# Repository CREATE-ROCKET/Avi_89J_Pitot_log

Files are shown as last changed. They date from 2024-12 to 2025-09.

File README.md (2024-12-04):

# 89Jのピトー管基板用です

## 現在の予定
基本的にFree RTOSでのタスク機能を利用して
 - ピトー管からデーターを得るタスク
 - それを他に送るタスク(CAN、 SPIFlash、 パリティ)
 - CANを送信するタスク
 - SPIFlashに書き込むタスク
 - MicroSDに書き込むタスク

の4つをタスクとして動作させたい。
MicroSDにログを書き込むようのタスクも作るか考え中

```mermaid
flowchart TB
  node_1("getPitotData")
  node_2("sendDataToEveryIC")
  node_3("writeDataToFlash")
  node_4("sendDataByCan")
  node_6("writeDataToSD")
  node_2 --> node_4
  node_2 --> node_3
  node_1 --> node_2
  node_2 --> node_6
```

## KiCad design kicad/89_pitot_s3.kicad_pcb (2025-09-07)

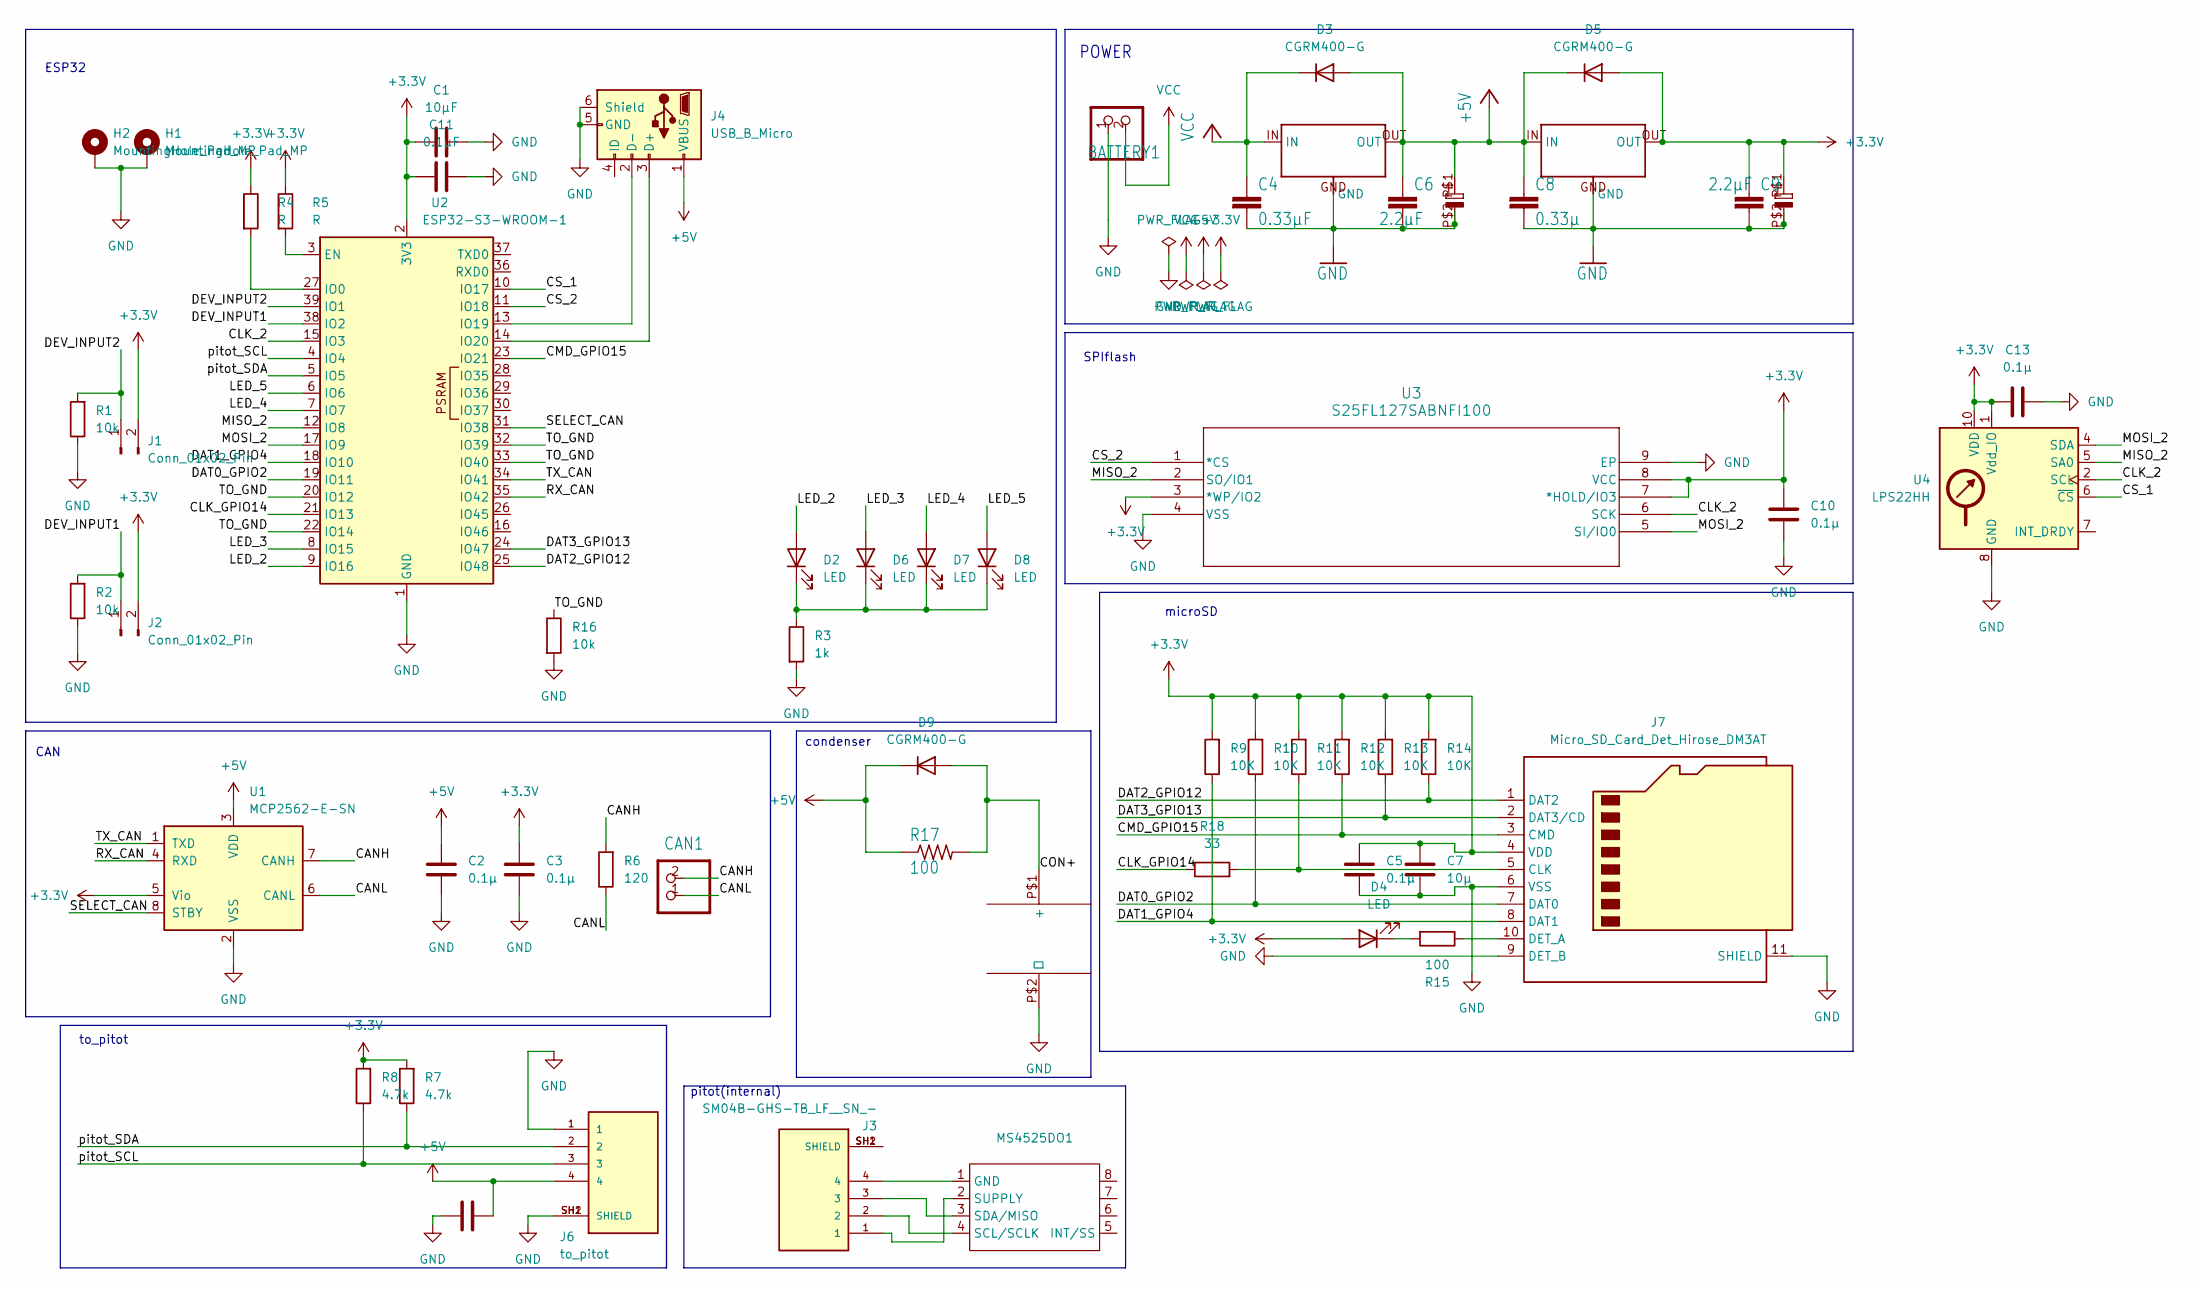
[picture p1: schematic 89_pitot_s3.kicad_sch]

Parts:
BATTERY1: L2; ILG2pin
C1: 10μF; C_0603_1608Metric
C2, C3, C5, C10, C12, C13: 0.1μ; C_0603_1608Metric
C4: 0.33μF; R_0603_1608Metric
C6, C9: 2.2μF; R_0603_1608Metric
C7: 10μ; D_0603_1608Metric
C8: 0.33μ; R_0603_1608Metric
C11: 0.1μF; C_0603_1608Metric
CAN1: ILG2pin
D2, D4, D6, D7, D8: LED; LED_0603_1608Metric
D3, D5, D9: CGRM400-G; D_0603_1608Metric_Pad1.05x0.95mm_HandSolder
H1, H2: MountingHole_Pad_MP; SolderWirePad_1x01_SMD_1x2mm
J1, J2: Conn_01x02_Pin; PinHeader_1x02_P2.54mm_Vertical
J3: SM04B-GHS-TB_LF__SN_-; JST_SM04B-GHS-TB_LF__SN_-; PARTREV NA
J4: USB_B_Micro; USB_Micro-B_Molex_47346-0001
J6: to_pitot; JST_GH_SM04B-GHS-TB_1x04-1MP_P1.25mm_Horizontal; PARTREV NA
J7: Micro_SD_Card_Det_Hirose_DM3AT; microSD_HC_Hirose_DM3AT-SF-PEJM5
MS4525DO1: (no value)
R1, R2: 10k; R_0603_1608Metric
R3: 1k; R_0603_1608Metric
R4, R5: R; C_0603_1608Metric
R6: 120; R_0603_1608Metric
R7, R8: 4.7k; R_0603_1608Metric
R9, R10, R11, R12, R13, R14: 10K; R_0603_1608Metric
R15: 100; R_0603_1608Metric
R16: 10k; C_0603_1608Metric
R17: 100; C_0603_1608Metric
R18: 33; C_0603_1608Metric
U1: MCP2562-E-SN; SOIC-8_3.9x4.9mm_P1.27mm
U2: ESP32-S3-WROOM-1
U3: S25FL127SABNFI100; SOC008_SPA
U4: LPS22HH; ST_HLGA-10_2x2mm_P0.5mm_LayoutBorder3x2y
U$1, U$3: NJM2391DL1-33; DPAK229P990X238-4N
U$2, U$4: UCD0J470MCL1GS; PCAP_5x5.8-ELECT_NCA
U$5: VEC5R4355QG-I; C_Disc_D8.0mm_W5.0mm_P5.00mm

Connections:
+3.3V: C1.1, C3.1, C5.1, C7.1, C9.1, C10.1, C11.1, C13.1, D4.2 (A), D5.2 (A), J1.2, J2.2, J7.4 (VDD), R4.1, R5.1, R7.2, R8.2, R9.2, R10.2, R11.2, R12.2, R13.2, R14.2, U1.5 (Vio), U2.2 (3V3), U3.3 (*WP/IO2), U3.7 (*HOLD/IO3), U3.8 (VCC), U4.1 (Vdd_IO), U4.10 (VDD), U$3.OUT, U$4.P$1 (+)
+5V: C2.1, C6.1, C8.1, C12.2, D3.2 (A), D5.1 (K), D9.1 (K), J4.1 (VBUS), J6.4, R17.1, U1.3 (VDD), U$1.OUT, U$2.P$1 (+), U$3.IN
/CANH: CAN1.2, R6.2, U1.7 (CANH); also elsewhere on the board
/CANL: CAN1.1, R6.1, U1.6 (CANL); also elsewhere on the board
/CLK_2: U2.15 (IO3), U3.6 (SCK), U4.2 (SCL)
/CLK_GPIO14: R18.1, U2.21 (IO13)
/CMD_GPIO15: J7.3 (CMD), R12.1, U2.23 (IO21)
/CON+: D9.2 (A), R17.2, U$5.P$1 (+)
/CS_1: U2.10 (IO17), U4.6 (~CS)
/CS_2: U2.11 (IO18), U3.1 (*CS)
/DAT0_GPIO2: J7.7 (DAT0), R10.1, U2.19 (IO11)
/DAT1_GPIO4: J7.8 (DAT1), R9.1, U2.18 (IO10)
/DAT2_GPIO12: J7.1 (DAT2), R14.1, U2.25 (IO48)
/DAT3_GPIO13: J7.2 (DAT3/CD), R13.1, U2.24 (IO47)
/DEV_INPUT1: J2.1, R2.2, U2.38 (IO2)
/DEV_INPUT2: J1.1, R1.2, U2.39 (IO1)
/LED_2: D2.2 (A), U2.9 (IO16)
/LED_3: D6.2 (A), U2.8 (IO15)
/LED_4: D7.2 (A), U2.7 (IO7)
/LED_5: D8.2 (A), U2.6 (IO6)
/MISO_2: U2.12 (IO8), U3.2 (SO/IO1), U4.5 (SA0)
/MOSI_2: U2.17 (IO9), U3.5 (SI/IO0), U4.4 (SDA)
/RX_CAN: U1.4 (RXD), U2.35 (IO42)
/SELECT_CAN: U1.8 (STBY), U2.31 (IO38)
/TO_GND: R16.1, U2.20 (IO12), U2.22 (IO14), U2.32 (IO39), U2.33 (IO40)
/TX_CAN: U1.1 (TXD), U2.34 (IO41)
/pitot_SCL: J6.3, R8.1, U2.4 (IO4)
/pitot_SDA: J6.2, R7.1, U2.5 (IO5)
GND: BATTERY1.1, C1.2, C2.2, C3.2, C4.2, C5.2, C6.2, C7.2, C8.2, C9.2, C10.2, C11.2, C12.1, C13.2, H1.MP, H2.MP, J4.5 (GND), J4.6 (Shield), J6.1, J6.SH1 (SHIELD), J6.SH2 (SHIELD), J7.6 (VSS), J7.9 (DET_B), J7.11 (SHIELD), R1.1, R2.1, R3.2, R16.2, U1.2 (VSS), U2.1 (GND), U2.40 (GND), U2.41 (GND), U3.4 (VSS), U3.9 (EP), U4.3 (GND), U4.8 (GND), U4.9 (GND), U$1.GND, U$2.P$2 (ー), U$3.GND, U$4.P$2 (ー), U$5.P$2 (ー); also elsewhere on the board
unnamed: D2.1 (K), D6.1 (K), D7.1 (K), D8.1 (K), R3.1
unnamed: D4.1 (K), R15.2
unnamed: J3.1, MS4525DO1.2 (SUPPLY)
unnamed: J3.2, MS4525DO1.4 (SCL/SCLK)
unnamed: J3.3, MS4525DO1.3 (SDA/MISO)
unnamed: J3.4, MS4525DO1.1 (GND)
unnamed: J3.SH1 (SHIELD), J3.SH2 (SHIELD)
unnamed: J4.3 (D+), U2.14 (IO20)
unnamed: J4.2 (D-), U2.13 (IO19)
unnamed: J7.5 (CLK), R11.1, R18.2
unnamed: J7.10 (DET_A), R15.1
unnamed: R5.2, U2.3 (EN)
unnamed: R4.2, U2.27 (IO0)
VCC: BATTERY1.2, C4.1, D3.1 (K), U$1.IN; also elsewhere on the board

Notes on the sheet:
POWER
pitot(internal)
condenser
microSD
ESP32
to_pitot
SPIflash
CAN

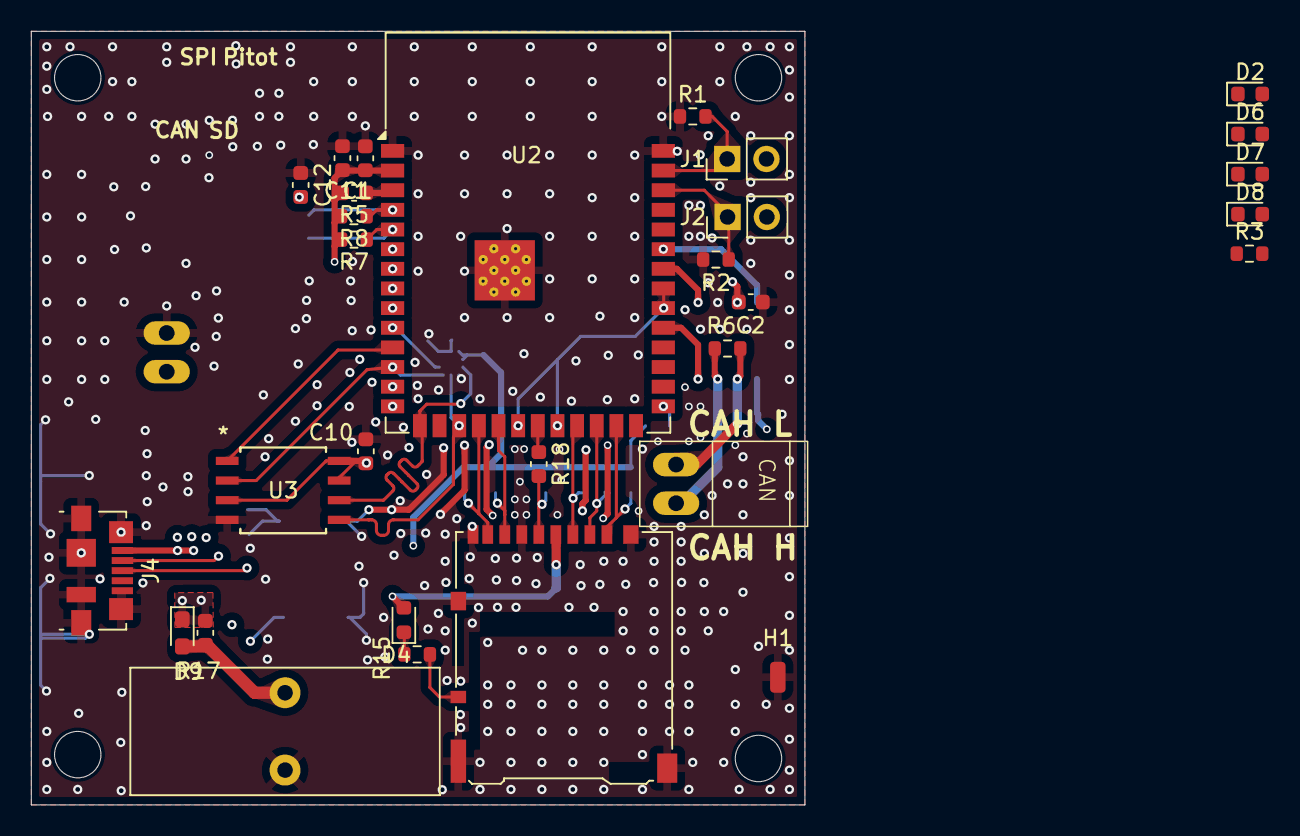
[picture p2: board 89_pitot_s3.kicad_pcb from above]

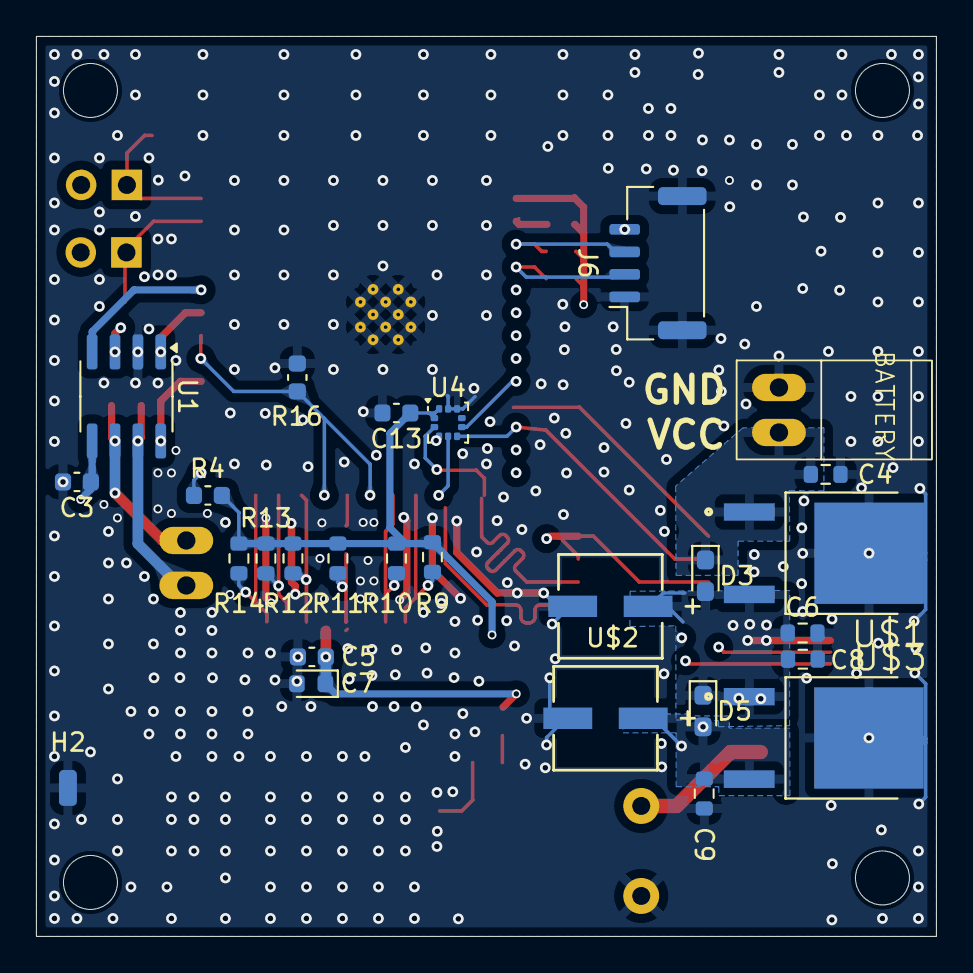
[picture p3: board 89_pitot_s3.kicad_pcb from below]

Board: 8 copper layers, 50.0 x 50.0 mm, 57 parts (27 on the bottom side), 38 nets.

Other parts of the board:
BATTERY: L2; ILG2pin
CAN: ILG2pin

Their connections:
/CANH: CAN.2; also elsewhere on the board
/CANL: CAN.1; also elsewhere on the board
GND: BATTERY.1; also elsewhere on the board
VCC: BATTERY.2; also elsewhere on the board

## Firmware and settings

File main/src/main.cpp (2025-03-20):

// 89ピトー管基板用のコードです。
//
// ピトー管用I2C通信
//    SDA:    IO21
//    SCL:    IO22
//
// SPI flash
//    CS:     IO5
//    CLK:    IO18
//    MOSI:   IO23
//    MISO:   IO19
//
// SD_MMC
//    CLK:    IO14
//    DAT0:   IO2
//    DAT1:   IO4
//    DAT2:   IO12
//    DAT3:   IO13
//    CMD:    IO15
//
// CAN
//    TX:     IO25
//    RX:     IO26
//    SELECT: IO33
//
// LED
//    IO27
//    IO32
//
// DEBUG_INPUT
//    IO17    task1,

#include <Arduino.h>
#include <esp_task_wdt.h>
#include "lib.h"
#include "debug.h"
#include "task_queue.h"
#include "task.h"
#include "panic_wrapper.h"
#include "common_task.h"
#include "interfaces/pitot.h"
#include "interfaces/SD_fast.h"
#include "interfaces/flash.h"
#include "interfaces/CAN_MCP2562.h"
#include "freertos/task.h"

// task handle
TaskHandle_t getPitotDataTaskHandle;      // pitotからデータを取得し、それをsendDataToEveryICへ送る 優先度 -1
TaskHandle_t sendDataToEveryICTaskHandle; // getPitotDataから得たデータを各端末に送る
TaskHandle_t writeDataToFlashTaskHandle;  // SPI_Flashにデーターを書き込む
TaskHandle_t makeParityTaskHandle;        // sendDataToEveryICから受け取ったデータを加工してwriteDataToSDに送る
TaskHandle_t writeDataToSDTaskHandle;     // makeParityから受け取ったデータやログをMicroSDに書き込む
TaskHandle_t sendDataByCanTaskHandle;     // sendDataToEveryICから受け取ったデータを送る

// queue handle
QueueHandle_t PitotToDistributeQueue;  // PitotからsendDataにデータを渡すQueue
QueueHandle_t DistributeToFlashQueue;  // sendDataからFlashにデータを渡すQueue
QueueHandle_t DistributeToParityQueue; // sendDataからParityにデータを渡すQueue
QueueHandle_t ParityToSDQueue;         // ParityからSDにデータを渡すQueue
QueueHandle_t DistributeToCanQueue;    // sendDataからCanにデータを渡すQueue

// 初期化が成功したかどうかを表す
// pitotが0
// SDが1
// flashが2
// CANが3
uint8_t IsInitSuccess = 0;

#ifdef DEBUG

void pr_feature_fg()
{
  Serial.println("feature flag");
  Serial.print("Pitot: \t");
#ifdef PITOT
  Serial.println("enabled");
#else
  Serial.println("disenabled");
#endif
  Serial.print("SD: \t");
#ifdef SD_FAST
  Serial.println("enabled");
#else
  Serial.println("disenabled");
#endif
  Serial.print("SPIFlash: \t");
#ifdef SPIFLASH
  Serial.println("enabled");
#else
  Serial.println("disenabled");
#endif
  Serial.print("Can: \t");
#ifdef CAN_MCP2562
  Serial.println("enabled");
#else
  Serial.println("disenabled");
#endif
}

void pr_reset_reason()
{
  esp_reset_reason_t reason = esp_reset_reason();
  switch (reason)
  {
  case ESP_RST_UNKNOWN:
    Serial.println("Reset reason can not be determined");
    break;
  case ESP_RST_POWERON:
    Serial.println("Reset due to power-on event");
    break;
  case ESP_RST_EXT:
    Serial.println("Reset by external pin (not applicable for ESP32)");
    break;
  case ESP_RST_SW:
    Serial.println("Software reset via esp_restart");
    break;
  case ESP_RST_PANIC:
    Serial.println("Software reset due to exception/panic");
    break;
  case ESP_RST_INT_WDT:
    Serial.println("Reset (software or hardware) due to interrupt watchdog");
    break;
  case ESP_RST_TASK_WDT:
    Serial.println("Reset due to task watchdog");
    break;
  case ESP_RST_WDT:
    Serial.println("Reset due to other watchdogs");
    break;
  case ESP_RST_DEEPSLEEP:
    Serial.println("Reset after exiting deep sleep mode");
    break;
  case ESP_RST_BROWNOUT:
    Serial.println("Brownout reset (software or hardware)");
    break;
  case ESP_RST_SDIO:
    Serial.println("Reset over SDIO");
    break;
  default:
    break;
  }
}

void vApplicationStackOverflowHook(TaskHandle_t *xTask, portCHAR *taskname)
{
  error_log("Stack Over Flow Detected!!!: %s", taskname);
}

#endif

// loop関数のスタックサイズを決める関数
size_t getArduinoLoopTaskStackSize(void)
{
  return 8192; // weak attribute で定義されているため再定義している
}

void setup()
{
  int result;
  int error_num = 0; // 2以上ならcriticalな問題が発生したと判断してreboot
#ifdef DEBUG

  Serial.begin(115200);
  while (!Serial)
  {
    delay(10);
  }
  Serial.println("plz press some key");
  while (true)
  {
    if (Serial.available())
      break;
    delay(10);
  }

  Serial.println("Debug mode is on.");
  pr_feature_fg();
  pr_reset_reason();

  Serial.printf("Chip model: %s, %u MHZ, %hu cores\n", ESP.getChipModel(), ESP.getCpuFreqMHz(), ESP.getChipCores());
  Serial.printf("Free heap: %u / %u %u max block\n", ESP.getFreeHeap(), ESP.getHeapSize(), ESP.getMaxAllocHeap());
  Serial.printf("Free PSRAM: %u / %u %u max block\n", ESP.getFreePsram(), ESP.getPsramSize(), ESP.getMaxAllocPsram());
#endif
#if IS_S3
  pinMode(led::LED, OUTPUT);
  pinMode(led::LED_PITOT, OUTPUT);
  pinMode(led::LED_FLASH, OUTPUT);
  pinMode(led::LED_SD, OUTPUT);
  pinMode(led::LED_CAN, OUTPUT);
  pinMode(debug::DEBUG_INPUT1, INPUT);
  pinMode(debug::DEBUG_INPUT2, INPUT);
  digitalWrite(led::LED, HIGH);
  digitalWrite(led::LED_PITOT, LOW);
  digitalWrite(led::LED_SD, LOW);
  digitalWrite(led::LED_FLASH, LOW);
  digitalWrite(led::LED_CAN, LOW);
#else
  pinMode(led::LED1, OUTPUT);
  pinMode(led::LED2, OUTPUT);
  pinMode(debug::DEBUG_INPUT, INPUT);
  digitalWrite(led::LED1, LOW);
  digitalWrite(led::LED2, HIGH);
#endif

  // Queue作成 error_logを利用したいので上に置いてる
  PitotToDistributeQueue = xQueueCreate(20, sizeof(Data *));
  ParityToSDQueue = xQueueCreate(30, sizeof(char *));
  DistributeToFlashQueue = xQueueCreate(5, sizeof(u_int8_t *));
  DistributeToParityQueue = xQueueCreate(5, sizeof(Data *));
  DistributeToCanQueue = xQueueCreate(5, sizeof(uint8_t *));
  error_log("init: %lld", esp_timer_get_time());
  error_t why_reset = esp_reset_reason();
  if (ESP_RST_PANIC == why_reset)
  {
    cmn_task::blinkLED_start(1, 1000);
    char backtrace_str[1024];
    uint16_t offset = 0;
    offset += sprintf(backtrace_str + offset, "Backtrace: ");
    for (uint8_t i = 0; i < STACK_DEPTH; i++)
    {
      if (s_exception_info.pc[i] != 0 && s_exception_info.sp[i] != 0)
      {
        offset += sprintf(backtrace_str + offset, "0x%08x:0x%08x ", (unsigned int)s_exception_info.pc[i], (unsigned int)s_exception_info.sp[i]);
      }
    }
    error_log("esp was reset due to panic\nBacktrace: %s\n", backtrace_str);
  }
  else if (ESP_RST_SW == why_reset)
  {
    cmn_task::blinkLED_start(1, 1000);
    error_log("restart due to esp_restart at %lldms", esp_timer_get_time());
  }

#if !defined(DEBUG) || defined(CAN_MCP2562)
  result = can::init();
  if (result)
  {
    error_log("can_init failed: %d", result);
  }
  else
  {
#if IS_S3
    digitalWrite(led::LED_CAN, HIGH);
#endif
    xTaskCreateUniversal(can::sendDataByCAN, "sendDataByCAN", 8192, NULL, 6, &sendDataByCanTaskHandle, APP_CPU_NUM);
    IsInitSuccess += 1 << 3;
  }
  can::canSend('i');
#endif
#if !defined(DEBUG) || defined(SD_FAST)
  result = sd_mmc::init();
  if (result)
  {
    pr_debug("SD_init failed: %d", result);
    ++error_num;
  }
  else
  {
#if IS_S3
    digitalWrite(led::LED_SD, HIGH);
#endif
    result = sd_mmc::makeNewFile();
    if (result)
    {
      pr_debug("Can't make new file: %d", result);
    }
    else
    {
#if IS_S3
      attachInterrupt(digitalPinToInterrupt(debug::DEBUG_INPUT1), sd_mmc::onButton, RISING);
#else
      attachInterrupt(digitalPinToInterrupt(debug::DEBUG_INPUT), sd_mmc::onButton, RISING);
#endif
      xTaskCreateUniversal(sd_mmc::writeDataToSD, "writeDataToSD", 8192, NULL, 6, &writeDataToSDTaskHandle, APP_CPU_NUM);
      IsInitSuccess += 1 << 1;
    }
  }
#endif

#if !defined(DEBUG) || defined(SPIFLASH)
  result = flash::init();
  if (result)
  {
    error_log("flash_init failed: %d", result);
    ++error_num;
  }
  else
  {
#if IS_S3
    digitalWrite(led::LED_FLASH, HIGH);
#endif
    xTaskCreateUniversal(flash::writeDataToFlash, "writeDataToFlash", 8192, NULL, 6, &writeDataToFlashTaskHandle, PRO_CPU_NUM);
    IsInitSuccess += 1 << 2;
  }
#endif

#if !defined(DEBUG) || defined(PITOT)
#if IS_S3
  digitalWrite(led::LED_PITOT, HIGH);
#endif
  xTaskCreateUniversal(pitot::getPitotData, "getPitotDataTask", 4096, NULL, 8, &getPitotDataTaskHandle, PRO_CPU_NUM);
  IsInitSuccess += 1;
#else
  xTaskCreateUniversal(task::createData, "createDataForTest", 2048, NULL, 8, &getPitotDataTaskHandle, PRO_CPU_NUM);
#endif

  if (error_num >= 2)
  {
    error_log("fatal error occurred!! rebooting ....");
    esp_restart(); // 再起動する
  }
  pr_debug("done all init");

  xTaskCreateUniversal(sd_mmc::makeParity, "makeParity", 8192, NULL, 6, &makeParityTaskHandle, APP_CPU_NUM);

  xTaskCreateUniversal(task::distribute_data, "distributeData", 8192, NULL, 7, &sendDataToEveryICTaskHandle, APP_CPU_NUM);

  pr_debug("all done!!!");

#if IS_S3
  digitalWrite(led::LED, LOW);
#else
  digitalWrite(led::LED1, HIGH);
  digitalWrite(led::LED2, LOW);
#endif
}

void loop()
{
#ifndef DEBUG
  vTaskDelay(10000); // cpu を使いすぎないように
#else
  vTaskDelay(1000);
  unsigned int stackHighWaterMark;

  stackHighWaterMark = uxTaskGetStackHighWaterMark(getPitotDataTaskHandle);
  error_log("[LOG] remain of getPitotData stack is: %u\n", stackHighWaterMark);

  stackHighWaterMark = uxTaskGetStackHighWaterMark(sendDataToEveryICTaskHandle);
  error_log("[LOG] remain of sendDataToEveryIC stack is: %u\n", stackHighWaterMark);

  stackHighWaterMark = uxTaskGetStackHighWaterMark(writeDataToFlashTaskHandle);
  error_log("[LOG] remain of writeDataToFlash stack is: %u\n", stackHighWaterMark);

  stackHighWaterMark = uxTaskGetStackHighWaterMark(makeParityTaskHandle);
  error_log("[LOG] remain of makeParity stack is: %u\n", stackHighWaterMark);

  stackHighWaterMark = uxTaskGetStackHighWaterMark(writeDataToSDTaskHandle);
  error_log("[LOG] remain of writeDataToSD stack is: %u\n", stackHighWaterMark);

  stackHighWaterMark = uxTaskGetStackHighWaterMark(sendDataByCanTaskHandle);
  error_log("[LOG] remain of sendDataByCan stack is: %u\n", stackHighWaterMark);

#endif
}

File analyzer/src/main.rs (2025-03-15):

//#!/usr/bin/env -S cargo +nightly -q -Zscript
/*
---
[package]
name = "rust"
version = "0.1.0"
edition = "2024"

[dependencies]
clap = { version = "4.5.31", features = ["derive"] }
csv = "1.3.1"
plotters = "0.3.7"
---
*/

// --------------------------------------------------------------------
// pitot data analyzer written in rust
// --------------------------------------------------------------------

extern crate clap;
extern crate csv;
extern crate plotters;
use clap::Parser;
use plotters::{
    chart::ChartBuilder,
    prelude::IntoDrawingArea,
    style::{IntoFont, RED, WHITE},
};
use std::fs::File;

/// ピトー管のデータを解析するプログラム
#[derive(Parser, Debug)]
#[command(version, about, long_about = None)]
struct Args {
    /// データが入っているファイルのパス
    #[arg(short, long, default_value_t = String::from("./data.csv"))]
    file_path: String,

    /// 解析したデータを入れるファイル名
    #[arg(short, long, default_value_t = String::from("./out/figure1.png"))]
    output: String,

    /// 打ち上げ時の圧力
    #[arg(short, long, default_value_t = 101.33E3)]
    static_pascal: f32,
}

fn graph_print(
    x: Vec<i64>,
    y: Vec<f32>,
    graph_name: &str,
    output_name: &str,
) -> Result<(), Box<dyn std::error::Error>> {
    let width = 1080; // 横
    let height = 720; // 縦
    let graph_path_name = format!("{}_{}.png", output_name, graph_name);
    let root = plotters::prelude::BitMapBackend::new(&graph_path_name, (width, height))
        .into_drawing_area();
    root.fill(&WHITE)?;

    // y軸の最大最小値を算出
    let (y_min, y_max) = y
        .iter()
        .fold((0.0 / 0.0, 0.0), |(m, n), v| (v.min(m), v.max(n)));

    let caption = graph_name;
    let font = ("sans-serif", 20);

    let mut chart = ChartBuilder::on(&root)
        .caption(caption, font.into_font())
        .margin(20)
        .x_label_area_size(16)
        .y_label_area_size(42)
        .build_cartesian_2d(*x.first().unwrap()..*x.last().unwrap(), y_min..y_max)?;

    chart.configure_mesh().draw()?;
    let line_series =
        plotters::series::LineSeries::new(x.iter().zip(y.iter()).map(|(x, y)| (*x, *y)), &RED);
    chart.draw_series(line_series)?;

    Ok(())
}

fn main() {
    // ファイル名を受け取る
    let args = Args::parse();

    // file_path をパスとして csv の読み取り
    let pitot_data = File::open(args.file_path).expect("invalid file path");
    let mut pitot_data = csv::Reader::from_reader(pitot_data);
    let mut time_data: Vec<i64> = Vec::new();
    let mut pascal_data: Vec<f32> = Vec::new();
    let mut temperature_data: Vec<f32> = Vec::new();
    for result in pitot_data.records() {
        let record = result.unwrap();
        // 読み取ったcsvのStringRecordからtemperatureとpascal、 timeを読み取る
        time_data.push(
            record[0]
                .trim()
                .parse::<i64>()
                .expect("failed to parse time data"),
        );
        pascal_data.push(
            record[1]
                .trim()
                .parse::<f32>()
                .expect("failed to parse pascal data"),
        );
        temperature_data.push(
            record[2]
                .trim()
                .parse::<f32>()
                .expect("failed to parse temperature data"),
        );
    }

    assert_eq!(time_data.len(), pascal_data.len());
    assert_eq!(time_data.len(), temperature_data.len());

    let mut speed_data: Vec<f32> = Vec::new();
    for (pascal, temp) in pascal_data
        .clone()
        .into_iter()
        .zip(temperature_data.clone().into_iter())
    {
        // 密度計算
        let rho = 0.0034837 * args.static_pascal / (temp + 273.15);
        let result = (2.0 * pascal / rho).sqrt();
        speed_data.push(result);
    }

    assert_eq!(time_data.len(), speed_data.len());

    graph_print(
        time_data.clone(),
        temperature_data.clone(),
        "temp_data",
        &args.output,
    )
    .unwrap();
    graph_print(
        time_data.clone(),
        pascal_data.clone(),
        "pascal_data",
        &args.output,
    )
    .unwrap();
    graph_print(
        time_data.clone(),
        speed_data.clone(),
        "speed_data",
        &args.output,
    )
    .unwrap();

    let mut speed_data_limited: Vec<f32> = Vec::new();
    let mut time_data_limited: Vec<i64> = Vec::new();

    for (speed, time) in speed_data
        .clone()
        .into_iter()
        .zip(time_data.clone().into_iter())
    {
        if speed > 10.0 {
            speed_data_limited.push(speed);
            time_data_limited.push(time);
        }
    }

    graph_print(
        time_data_limited.clone(),
        speed_data_limited.clone(),
        "speed_data_lim",
        &args.output,
    )
    .unwrap();
}

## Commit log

2024-10-04 initial commit SD SPI flash test
2024-11-30 実機で動作用コードを書き始めた。現在、initはすべて書き終えた
2024-12-04 [add] ピトー管とFlash、SDに関しては一旦書き終わった
2024-12-10 microSDのゲートキーパータスクを作成 詳細な変更点 - Queueで渡される実体をポインタに変更 - xTaskはSuspendせずにxQueueReceiveの待ち時間を無制限とすることにする xQueueReceiveの待ち時間はvTaskDelayと同等なはず - microSDへの書き込み用のゲートキーパータスクを作成 - microSDへlogを書き込むことにした。 - erro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
    [SD_fast.cpp, flash.cpp, lib.h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]
2024-12-11 [fix]error_logを動作させた。 snprintfがうまく動作しないため、悩み中。
2024-12-12 [fix]distributeToEveryICTaskHandleが動作しないのを修正 Union型が悪さしてた
2025-01-04 [add] print flash old data
2025-01-09 [fix] critical sectionはwatch dog timerでpanicする
    [SD_fast.cpp, flash.cpp, lib.h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]
2025-01-12 [add] esp32 s3 support (WIP)
2025-01-24 [fix] esp32 panicked when SD init returned 1 or 2
    [SD_fast.cpp]
2025-02-05 [add] ESP32 S3 support
2025-02-15 [add] esp32 s3 support (MicroSD)
2025-03-09 [fix] fix some problems
    [common_task.cpp, lib.h, main.cpp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]
2025-03-14 [fix] watch dog triggered
    [flash.cpp, lib.h, main.cpp]
2025-03-15 [fix] wrong air density at data analyzer
    [main.rs]
2025-03-16 [add] SPIFFS support
    [partitions.csv]
2025-03-19 [add] SPIFFS support (WIP)
    [partitions.csv]
2025-03-19 [add] SPIFFS by arduino library
2025-03-19 [fix] SPIFFS error (WIP)
    [partitions.csv]
2025-03-20 [fix] flash run (WIP)
    [SD_fast.cpp, flash.cpp, main.cpp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]
2025-03-20 [fix] flash not running
    [flash.cpp]
2025-03-22 [fix] flash log (Not working)
    [flash.cpp]
2025-09-07 [add] kicad file
    [89_pitot_s3.kicad_pcb, 89_pitot_s3.kicad_sch]
